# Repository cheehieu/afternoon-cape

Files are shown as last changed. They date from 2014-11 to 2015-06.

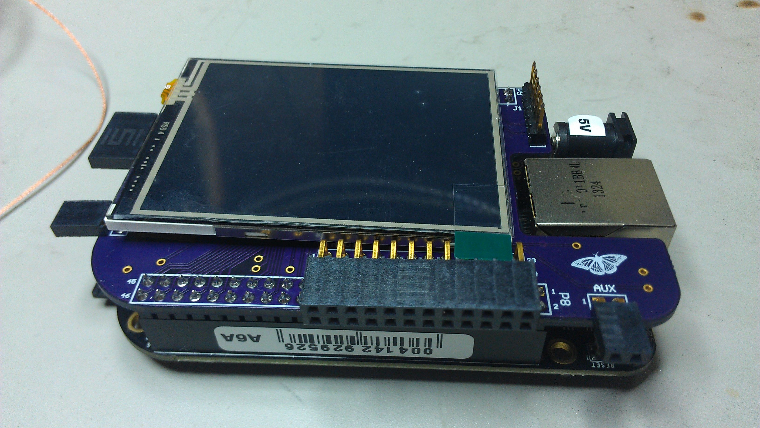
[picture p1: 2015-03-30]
images/pmcape_lcd.jpg

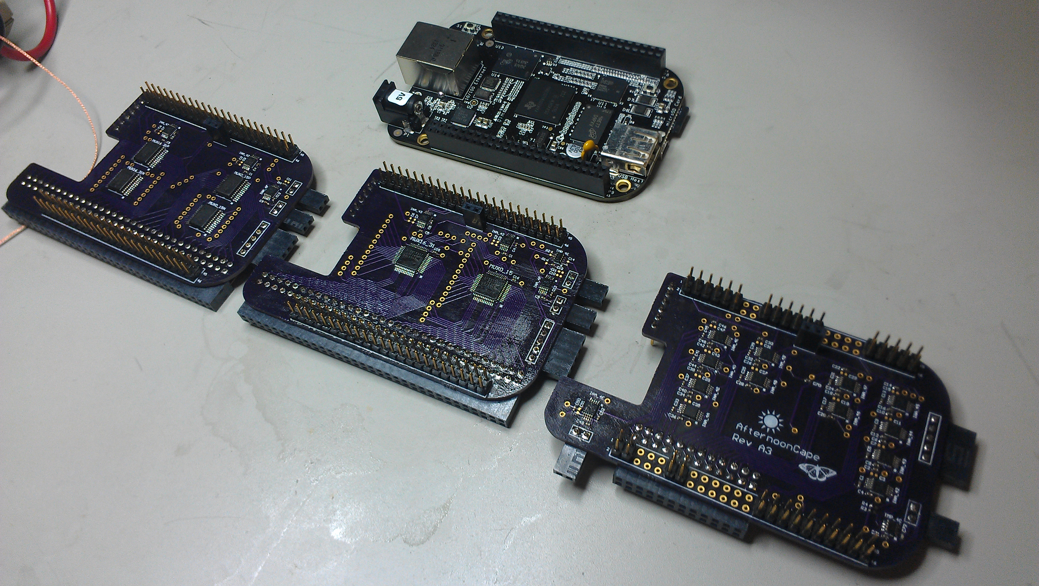
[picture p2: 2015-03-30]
images/capes_display_line.jpg

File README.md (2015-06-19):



## Overview
The AfternoonCape is a low-cost power monitoring (PM aka "afternoon") cape for the BeagleBone Black. It utilizes the INA226 instrumentation amplifier to accurately sample and monitor voltage, current, and power consumption of a given supply. This cape was created because of a need to quickly measure the active/leakage power of TI Sitara processors, without the use of hefty digital multimeter lab equipment. The AfternoonCape is a portable, relatively low-cost (~$20) solution and met the accuracy and sampling rate requirements of my team's power characterization and development tasks.

This project repository contains:

* Altium libraries, schematics, and board files
* PCB gerbers and drill files
* Bill of materials
* Standalone Bash scripts, Linux device drivers for INA226, TMP441
* GUI source, logging infrastructure

## Hardware
The AfternoonCape relies on special techniques and assumptions used for measuring power using current shunt monitors. For more information on current shunt monitors, please review this application note: [Current Shunt Monitors](http://www.ti.com/lit/ml/slyb194a/slyb194a.pdf). 



A few different board revisions were designed to test the accuracy/reliability of different signal path implementations. These "Alpha" revisions were comprised of the following: 

* *Rev. A1*: supports 32 channel inputs --> 4 discrete 16-to-1 analog muxes --> 2 instrumentation amplifiers sampling the voltage drop across a current shunt
* *Rev. A2*: supports 32 channel inputs --> 2 differential 16-to-1 analog muxes --> 2 instrumentation amplifiers sampling the voltage drop across a current shunt
* *Rev. A3*: supports 12 channel inputs --> 12 dedicated instrumentation amplifiers sampling the voltage drop across each current shunt --> LCD output

### Rev. A1:
This revision supports 32 channel inputs, which means it can measure the power consumption from 32 separate power supplies. The TI Sitara processors have advanced power designs to enable key power management techniques. One such technique is having several voltage and power domains, which can be individually turned off during periods of low activity (to save power). This type of design leads to a single-core processor having upwards of thirty separate power supplies. Thus, in order to measure total device power with voltage domain granularity, it is imperative that the measurement tool supports a sufficient amount of channel inputs.

Rev. A1 accomplishes this by utilizing the Texas Instruments CD74HC4067 16-channel analog multiplexer. This cape uses four of them to be exact. Four BBB GPIO's are interfaced to the mux select bits, which allow the proper analog signals to pass to the two INA2226's. Each INA226 handles 16 input channels. So, in order to take a total device power measurement, the cape must cycle through the mux select bits and log power data for each iteration.



Details:

* MUX_SEL0 (P8, pin 12), GPIO1_12 (0x44e10830, 0x30 offset, #44)
* MUX_SEL1 (P9, pin 23), GPIO1_17 (0x44e10844, 0x44 offset, #49)
* MUX_SEL2 (P9, pin 27), GPIO3_19 (0x44e109a4, 0x1a4 offset, #115)
* MUX_SEL3 (P9, pin 12), GPIO1_28 (0x44e10878, 0x78 offset, #60)
* INA_42 handles channels 0 through 15
* INA_43 handles channels 16 through 31
* Accuracy +/- %

### Rev. A2:
This revision also supports 32 channel inputs, but utilizes the Analog Devices ADG726 dual 16-channel analog multiplexer. The unique feature about the ADI mux vs. the TI mux is that the ADI mux can support differential operation. Thus, paired current shunt analog signals can be passed together through the same ICs. Also, only 2 of these muxes are needed due to its differential nature. The only major downside is that these ADG726 components are significantly more expensive than the TI counterpart.

Rev. A2 utilizes the same BBB GPIO control signals as mux select bits. Two INA226's are also used to measure data from 32 channel inputs.



Details:

* MUX_SEL0 (P8, pin 12)
* MUX_SEL1 (P9, pin 23)
* MUX_SEL2 (P9, pin 27)
* MUX_SEL3 (P9, pin 12)
* INA_42 handles channels 0 through 15
* INA_43 handles channels 16 through 31
* Accuracy +/- %

### Rev. A3:
This revision utilizes discrete INA226s for each channel input. It only supports 12 channels in total, but can take these power measurements simultaneously; no GPIO mux selects need to be cycled through before taking a measurement. With less channel inputs, there is routing space available for an LCD connector. The Newhaven Display International NHD-2.4-240320SF-CTXL#-FTN1 2.4" TFT LCD module was selected due to its small size and compatibility with the AM335x processor.





Details:

* INA42-INA4F handles channels 0 through 11
* Accuracy +/- %

### Rev. B1:
After testing all three Alpha revisions, it was determined that the TI analog mux (Rev. A1) was sufficiently accurate for active power characterization purposes. The Beta revision is a board shrink that incorporates lessons learned.

<!--img src="http://niftyhedgehog.com/afternoon-cape/images/pmcape_B1_oshpark_top.png" width="400"-->

<!--img src="http://niftyhedgehog.com/afternoon-cape/images/pmcape_B1_oshpark_bottom.png" width="400"-->

Details:

* Smaller vias
* Decoupling caps
* 16-channels
* LCD connector reposition
* FTDI connector for serial communication with a host PC
* AUX INA226 for dedicated system input power measurement
* PMDC connector for daisy chaining with PMDC daughter cards
* TMP441 for thermal diode junction temperature monitoring

## Software

### Standalone Bash Script
The standalone Bash script is a quick way to generate power numbers in a single instance. The script can be executed in a shell terminal on the BeagleBone Black running a [Debian](http://beagleboard.org/project/debian/) Linux distribution (has support for '[bc](http://www.gnu.org/software/bc/manual/html_mono/bc.html)' by default). The following is a high-level procedure for taking power measurements with the AfternoonCape:

1. Initialize INA226, GPIOs
2. Take shunt and bus voltage measurements for all supplies
3. Average the measurement values and store
4. Calculate power
5. Output to console and/or log file
6. Cleanup

```bash
...
#EVM Specific
declare -a SUPPLIES=('VDD_CORE' 'VDD_MPU' 'VDDS_DDR' 'V1_8D' 'V3_3D' 'VDDS_DDR_M
EM');
declare -a RES=(0.05 0.05 0.05 0.1 0.1 0.05);

...

echo $mux_sel0 > /sys/class/gpio/gpio44/value
echo $mux_sel1 > /sys/class/gpio/gpio49/value
echo $mux_sel2 > /sys/class/gpio/gpio115/value
echo $mux_sel3 > /sys/class/gpio/gpio60/value

...

#Collect shunt voltage measurement
shuntv=$(i2cget -y 1 $MUX1_INA_ADDR $SHUNTV_REG w)
let "temp = $shuntv >> 8"
let "temp2 = $shuntv << 8 | $temp"
let "shuntv = $temp2 & 0xffff"
shuntv=$(echo "$shuntv*0.0025" | bc)
MUX1_SHUNTV[j]=$shuntv

...

#Collect bus voltage measurement
busv=$(i2cget -y 1 $MUX1_INA_ADDR $BUSV_REG w)
let "temp = $busv >> 8"
let "temp2 = $busv << 8 | $temp"
let "busv = $temp2 & 0xffff"
busv=$(echo "$busv*0.00125" | bc)
MUX1_BUSV[k]=$busv

...

#Calculate power
SUPPLIES_CURRENT[i]=$(echo "${SUPPLIES_SHUNTV[i]}/${RES[i]}" | bc -l)
SUPPLIES_POWER[i]=$(echo "${SUPPLIES_CURRENT[i]}*${SUPPLIES_BUSV[i]}" |
total_power=$(echo "$total_power+${SUPPLIES_POWER[$x]}" | bc)
```

#### Usage:
```bash
root@beaglebone:~# ./testA2.sh
```

* loadmod afternoon-cape.ko EVM=am437xGP.txt
* Bash shell scripts using sysfs GPIO
* PMDC I2C protocol

### Accuracy
The afternoon-cape is a good, low-cost solution for getting "ballpark" power measurements. It works best in medium power use cases, where the current shunt voltage is >1mV; voltages on the micro-volt level are less accurately interpreted through the analog mux.
Some tests were done on the AM335x GP EVM to determine accuracy. Compared with a $1000+ Keithley Digital Multimeter with a $500 switching multiplexer module, the accuracy was comparable.

* Table comparison

## 3D
### AfternoonCape
<iframe width="640" height="480" src="https://sketchfab.com/models/0be9d541e4cb438f95a222904efbc644/embed" frameborder="0" allowfullscreen mozallowfullscreen="true" webkitallowfullscreen="true" onmousewheel=""></iframe>

<p style="font-size: 13px; font-weight: normal; margin: 5px; color: #4A4A4A;">
    <a href="https://sketchfab.com/models/0be9d541e4cb438f95a222904efbc644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" target="_blank" style="font-weight: bold; color: #1CAAD9;">AfternoonCape Rev. A3</a>
    by <a href="https://sketchfab.com/hieu?utm_source=oembed&utm_medium=embed&utm_campaign=0be9d541e4cb438f95a222904efbc644" target="_blank" style="font-weight: bold; color: #1CAAD9;">hieu</a>
    on <a href="https://sketchfab.com?utm_source=oembed&utm_medium=embed&utm_campaign=0be9d541e4cb438f95a222904efbc644" target="_blank" style="font-weight: bold; color: #1CAAD9;">Sketchfab</a>
</p>

### AfternoonCape Mounted on a BBB
<iframe width="640" height="480" src="https://sketchfab.com/models/db15b2ddc1894994b0886cfb680e3865/embed" frameborder="0" allowfullscreen mozallowfullscreen="true" webkitallowfullscreen="true" onmousewheel=""></iframe>

<p style="font-size: 13px; font-weight: normal; margin: 5px; color: #4A4A4A;">
    <a href="https://sketchfab.com/models/db15b2ddc1894994b0886cfb680e3865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" target="_blank" style="font-weight: bold; color: #1CAAD9;">AfternoonCape with BBB</a>
    by <a href="https://sketchfab.com/hieu?utm_source=oembed&utm_medium=embed&utm_campaign=db15b2ddc1894994b0886cfb680e3865" target="_blank" style="font-weight: bold; color: #1CAAD9;">hieu</a>
    on <a href="https://sketchfab.com?utm_source=oembed&utm_medium=embed&utm_campaign=db15b2ddc1894994b0886cfb680e3865" target="_blank" style="font-weight: bold; color: #1CAAD9;">Sketchfab</a>
</p>

## To Do:
* Update README with Accuracy and BOM materials
* Complete design for Rev. B, assemble & test
* Ensure script compatibility with latest v3.14 kernel
* Qt GUI and data logging over a network connection to a host PC
* Cost comparison with other *more expensive* solutions (DARA, ACME, PMDC, Spectrum Digital, Tick)

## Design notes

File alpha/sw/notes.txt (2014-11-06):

i2cdetect -y -r 1			#detect i2c slaves on bus 1 (I2C2 19/20)
#40: 40 41 42 43 -- -- -- -- -- -- -- -- -- -- -- -- 
#50: -- -- -- -- UU UU UU UU -- -- -- -- -- -- -- --

#SHUNT VOLTAGE = DEC(msbyte_lsbyte) * 2.5 UV
i2cget -y 1 0x40 0x01 w		#gets shunt voltage in hex 0x[lsbyte][msbyte]

#BUS VOLTAGE = DEC(msbyte_lsbyte) * 1.25 mV
i2cget -y 1 0x40 0x02 w		#gets bus voltage in hex 0x[lsbyte][msbyte]

#CALIBRATION to set shunt resistor value
#based on equation 1 in datasheet

#CURRENT and POWER need averaging to be set in config register

i2cset -y 1 0x40 0x00 0x2747 w	#sets config register to have averaging 64x

######################## THERMAL DIODE ########################
#TMP435 both address lines connected to GND
i2cset -y 1 0x4c 0x03 0x04 b#set extended range in config register
i2cget -y 1 0x4c 0x01 w		#read lowbyteHighbyte of remote temp

i2cd
#TMP441 both address lines connected to GND
i2cset -y 1 0x4c 0x9 0x4	#extended temp range
i2cset -y 1 0x4c 0xA 0x1C	#resistance, length
i2cset -y 1 0x4c 0xB 0x7	#conversion rate
i2cset -y 1 0x4c 0xC 0xf	#beta compensation
i2cset -y 1 0x4c 0x21 0x8	#n-correction

i2cget -y 1 0x4c 0x1 w		#read lowbyteHighbyte of remote sensor
i2cget -y 1 0x4c 0x1 b		#read Highbyte of remote sensor
i2cget -y 1 0x4c 0x11 b		#read lowbyte of remote sensor
i2cget -y 1 0x4c 0x0 w		#read lowbyteHighbyte of local sensor
i2cget -y 1 0x4c 0x0 b		#read Highbyte of local sensor
i2cget -y 1 0x4c 0x10 b		#read lowbyte of local sensor

i2cset -y 1 0x4c 0xFC 0x1	#software reset

#################### PSEUDO-CODE #############################
- If available, read in EVM config file
-- Parse for supply names, resistor values, etc.
-- Save values in structure
- Initialize INA226
- Initialize TMP441
- Initialize LCD
- Based on supply(s) selected, read corresponding channel, calculate power, store in structure
- Data dump feature
- Just temperature measurement feature (check boxes)
- AUX power
- Adjust speed of reading new data (1 Hz, 5 Hz, 10 Hz, 25 Hz, 50 Hz)
- GUI links to Wiki power consumption summaries
- Clear button

This is a small guide for those who want to write kernel drivers for I2C
or SMBus devices, using Linux as the protocol host/master (not slave).

To set up a driver, you need to do several things. Some are optional, and
some things can be done slightly or completely different. Use this as a
guide, not as a rule book!

General remarks
===============

Try to keep the kernel namespace as clean as possible. The best way to
do this is to use a unique prefix for all global symbols. This is
especially important for exported symbols, but it is a good idea to do
it for non-exported symbols too. We will use the prefix `foo_' in this
tutorial.

The driver structure
====================

Usually, you will implement a single driver structure, and instantiate
all clients from it. Remember, a driver structure contains general access
routines, and should be zero-initialized except for fields with data you
provide.  A client structure holds device-specific information like the
driver model device node, and its I2C address.

static struct i2c_device_id foo_idtable[] = {
	{ "foo", my_id_for_foo },
	{ "bar", my_id_for_bar },
	{ }
};

MODULE_DEVICE_TABLE(i2c, foo_idtable);

static struct i2c_driver foo_driver = {
	.driver = {
		.name	= "foo",
	},

	.id_table	= foo_idtable,
	.probe		= foo_probe,
	.remove		= foo_remove,
	/* if device autodetection is needed: */
	.class		= I2C_CLASS_SOMETHING,
	.detect		= foo_detect,
	.address_list	= normal_i2c,

	.shutdown	= foo_shutdown,	/* optional */
	.suspend	= foo_suspend,	/* optional */
	.resume		= foo_resume,	/* optional */
	.command	= foo_command,	/* optional, deprecated */
}

The name field is the driver name, and must not contain spaces.  It
should match the module name (if the driver can be compiled as a module),
although you can use MODULE_ALIAS (passing "foo" in this example) to add
another name for the module.  If the driver name doesn't match the module
name, the module won't be automatically loaded (hotplug/coldplug).

All other fields are for call-back functions which will be explained
below.

Extra client data
=================

Each client structure has a special `data' field that can point to any
structure at all.  You should use this to keep device-specific data.

	/* store the value */
	void i2c_set_clientdata(struct i2c_client *client, void *data);

	/* retrieve the value */
	void *i2c_get_clientdata(const struct i2c_client *client);

Note that starting with kernel 2.6.34, you don't have to set the `data' field
to NULL in remove() or if probe() failed anymore. The i2c-core does this
automatically on these occasions. Those are also the only times the core will
touch this field.

Accessing the client
====================

Let's say we have a valid client structure. At some time, we will need
to gather information from the client, or write new information to the
client.

I have found it useful to define foo_read and foo_write functions for this.
For some cases, it will be easier to call the i2c functions directly,
but many chips have some kind of register-value idea that can easily
be encapsulated.

The below functions are simple examples, and should not be copied
literally.

int foo_read_value(struct i2c_client *client, u8 reg)
{
	if (reg < 0x10)	/* byte-sized register */
		return i2c_smbus_read_byte_data(client, reg);
	else		/* word-sized register */
		return i2c_smbus_read_word_data(client, reg);
}

int foo_write_value(struct i2c_client *client, u8 reg, u16 value)
{
	if (reg == 0x10)	/* Impossible to write - driver error! */
		return -EINVAL;
	else if (reg < 0x10)	/* byte-sized register */
		return i2c_smbus_write_byte_data(client, reg, value);
	else			/* word-sized register */
		return i2c_smbus_write_word_data(client, reg, value);
}

Probing and attaching
=====================

The Linux I2C stack was originally written to support access to hardware
monitoring chips on PC motherboards, and thus used to embed some assumptions
that were more appropriate to SMBus (and PCs) than to I2C.  One of these
assumptions was that most adapters and devices drivers support the SMBUS_QUICK
protocol to probe device presence.  Another was that devices and their drivers
can be sufficiently configured using only such probe primitives.

As Linux and its I2C stack became more widely used in embedded systems
and complex components such as DVB adapters, those assumptions became more
problematic.  Drivers for I2C devices that issue interrupts need more (and
different) configuration information, as do drivers handling chip variants
that can't be distinguished by protocol probing, or which need some board
specific information to operate correctly.

Device/Driver Binding
---------------------

System infrastructure, typically board-specific initialization code or
boot firmware, reports what I2C devices exist.  For example, there may be
a table, in the kernel or from the boot loader, identifying I2C devices
and linking them to board-specific configuration information about IRQs
and other wiring artifacts, chip type, and so on.  That could be used to
create i2c_client objects for each I2C device.

I2C device drivers using this binding model work just like any other
kind of driver in Linux:  they provide a probe() method to bind to
those devices, and a remove() method to unbind.

	static int foo_probe(struct i2c_client *client,
			     const struct i2c_device_id *id);
	static int foo_remove(struct i2c_client *client);

Remember that the i2c_driver does not create those client handles.  The
handle may be used during foo_probe().  If foo_probe() reports success
(zero not a negative status code) it may save the handle and use it until
foo_remove() returns.  That binding model is used by most Linux drivers.

The probe function is called when an entry in the id_table name field
matches the device's name. It is passed the entry that was matched so
the driver knows which one in the table matched.

Device Creation
---------------

If you know for a fact that an I2C device is connected to a given I2C bus,
you can instantiate that device by simply filling an i2c_board_info
structure with the device address and driver name, and calling
i2c_new_device().  This will create the device, then the driver core will
take care of finding the right driver and will call its probe() method.
If a driver supports different device types, you can specify the type you
want using the type field.  You can also specify an IRQ and platform data
if needed.

Sometimes you know that a device is connected to a given I2C bus, but you
don't know the exact address it uses.  This happens on TV adapters for
example, where the same driver supports dozens of slightly different
models, and I2C device addresses change from one model to the next.  In
that case, you can use the i2c_new_probed_device() variant, which is
similar to i2c_new_device(), except that it takes an additional list of
possible I2C addresses to probe.  A device is created for the first
responsive address in the list.  If you expect more than one device to be
present in the address range, simply call i2c_new_probed_device() that
many times.

The call to i2c_new_device() or i2c_new_probed_device() typically happens
in the I2C bus driver. You may want to save the returned i2c_client
reference for later use.

Device Detection
----------------

Sometimes you do not know in advance which I2C devices are connected to
a given I2C bus.  This is for example the case of hardware monitoring
devices on a PC's SMBus.  In that case, you may want to let your driver
detect supported devices automatically.  This is how the legacy model
was working, and is now available as an extension to the standard
driver model.

You simply have to define a detect callback which will attempt to
identify supported devices (returning 0 for supported ones and -ENODEV
for unsupported ones), a list of addresses to probe, and a device type
(or class) so that only I2C buses which may have that type of device
connected (and not otherwise enumerated) will be probed.  For example,
a driver for a hardware monitoring chip for which auto-detection is
needed would set its class to I2C_CLASS_HWMON, and only I2C adapters
with a class including I2C_CLASS_HWMON would be probed by this driver.
Note that the absence of matching classes does not prevent the use of
a device of that type on the given I2C adapter.  All it prevents is
auto-detection; explicit instantiation of devices is still possible.

Note that this mechanism is purely optional and not suitable for all
devices.  You need some reliable way to identify the supported devices
(typically using device-specific, dedicated identification registers),
otherwise misdetections are likely to occur and things can get wrong
quickly.  Keep in mind that the I2C protocol doesn't include any
standard way to detect the presence of a chip at a given address, let
alone a standard way to identify devices.  Even worse is the lack of
semantics associated to bus transfers, which means that the same
transfer can be seen as a read operation by a chip and as a write
operation by another chip.  For these reasons, explicit device
instantiation should always be preferred to auto-detection where
possible.

Device Deletion
---------------

Each I2C device which has been created using i2c_new_device() or
i2c_new_probed_device() can be unregistered by calling
i2c_unregister_device().  If you don't call it explicitly, it will be
called automatically before the underlying I2C bus itself is removed, as a
device can't survive its parent in the device driver model.

Initializing the driver
=======================

When the kernel is booted, or when your foo driver module is inserted,
you have to do some initializing. Fortunately, just registering the
driver module is usually enough.

static int __init foo_init(void)
{
	return i2c_add_driver(&foo_driver);
}
module_init(foo_init);

static void __exit foo_cleanup(void)
{
	i2c_del_driver(&foo_driver);
}
module_exit(foo_cleanup);

The module_i2c_driver() macro can be used to reduce above code.

module_i2c_driver(foo_driver);

Note that some functions are marked by `__init'.  These functions can
be removed after kernel booting (or module loading) is completed.
Likewise, functions marked by `__exit' are dropped by the compiler when
the code is built into the kernel, as they would never be called.

Driver Information
==================

/* Substitute your own name and email address */
MODULE_AUTHOR("Frodo Looijaard <frodol@dds.nl>"
MODULE_DESCRIPTION("Driver for Barf Inc. Foo I2C devices");

/* a few non-GPL license types are also allowed */
MODULE_LICENSE("GPL");

Power Management
================

If your I2C device needs special handling when entering a system low
power state -- like putting a transceiver into a low power mode, or
activating a system wakeup mechanism -- do that in the suspend() method.
The resume() method should reverse what the suspend() method does.

These are standard driver model calls, and they work just like they
would for any other driver stack.  The calls can sleep, and can use
I2C messaging to the device being suspended or resumed (since their
parent I2C adapter is active when these calls are issued, and IRQs
are still enabled).

System Shutdown
===============

If your I2C device needs special handling when the system shuts down
or reboots (including kexec) -- like turning something off -- use a
shutdown() method.

Again, this is a standard driver model call, working just like it
would for any other driver stack:  the calls can sleep, and can use
I2C messaging.

Command function
================

A generic ioctl-like function call back is supported. You will seldom
need this, and its use is deprecated anyway, so newer design should not
use it.

Sending and receiving
=====================

If you want to communicate with your device, there are several functions
to do this. You can find all of them in <linux/i2c.h>.

If you can choose between plain I2C communication and SMBus level
communication, please use the latter. All adapters understand SMBus level
commands, but only some of them understand plain I2C!

Plain I2C communication
-----------------------

	int i2c_master_send(struct i2c_client *client, const char *buf,
			    int count);
	int i2c_master_recv(struct i2c_client *client, char *buf, int count);

These routines read and write some bytes from/to a client. The client
contains the i2c address, so you do not have to include it. The second
parameter contains the bytes to read/write, the third the number of bytes
to read/write (must be less than the length of the buffer, also should be
less than 64k since msg.len is u16.) Returned is the actual number of bytes
read/written.

	int i2c_transfer(struct i2c_adapter *adap, struct i2c_msg *msg,
			 int num);

This sends a series of messages. Each message can be a read or write,
and they can be mixed in any way. The transactions are combined: no
stop bit is sent between transaction. The i2c_msg structure contains
for each message the client address, the number of bytes of the message
and the message data itself.

You can read the file `i2c-protocol' for more information about the
actual I2C protocol.

SMBus communication
-------------------

	s32 i2c_smbus_xfer(struct i2c_adapter *adapter, u16 addr,
			   unsigned short flags, char read_write, u8 command,
			   int size, union i2c_smbus_data *data);

This is the generic SMBus function. All functions below are implemented
in terms of it. Never use this function directly!

	s32 i2c_smbus_read_byte(struct i2c_client *client);
	s32 i2c_smbus_write_byte(struct i2c_client *client, u8 value);
	s32 i2c_smbus_read_byte_data(struct i2c_client *client, u8 command);
	s32 i2c_smbus_write_byte_data(struct i2c_client *client,
				      u8 command, u8 value);
	s32 i2c_smbus_read_word_data(struct i2c_client *client, u8 command);
	s32 i2c_smbus_write_word_data(struct i2c_client *client,
				      u8 command, u16 value);
	s32 i2c_smbus_read_block_data(struct i2c_client *client,
				      u8 command, u8 *values);
	s32 i2c_smbus_write_block_data(struct i2c_client *client,
				       u8 command, u8 length, const u8 *values);
	s32 i2c_smbus_read_i2c_block_data(struct i2c_client *client,
					  u8 command, u8 length, u8 *values);
	s32 i2c_smbus_write_i2c_block_data(struct i2c_client *client,
					   u8 command, u8 length,
					   const u8 *values);

These ones were removed from i2c-core because they had no users, but could
be added back later if needed:

	s32 i2c_smbus_write_quick(struct i2c_client *client, u8 value);
	s32 i2c_smbus_process_call(struct i2c_client *client,
				   u8 command, u16 value);
	s32 i2c_smbus_block_process_call(struct i2c_client *client,
					 u8 command, u8 length, u8 *values);

All these transactions return a negative errno value on failure. The 'write'
transactions return 0 on success; the 'read' transactions return the read
value, except for block transactions, which return the number of values
read. The block buffers need not be longer than 32 bytes.

You can read the file `smbus-protocol' for more information about the
actual SMBus protocol.

General purpose routines
========================

Below all general purpose routines are listed, that were not mentioned
before.

	/* Return the adapter number for a specific adapter */
	int i2c_adapter_id(struct i2c_adapter *adap);

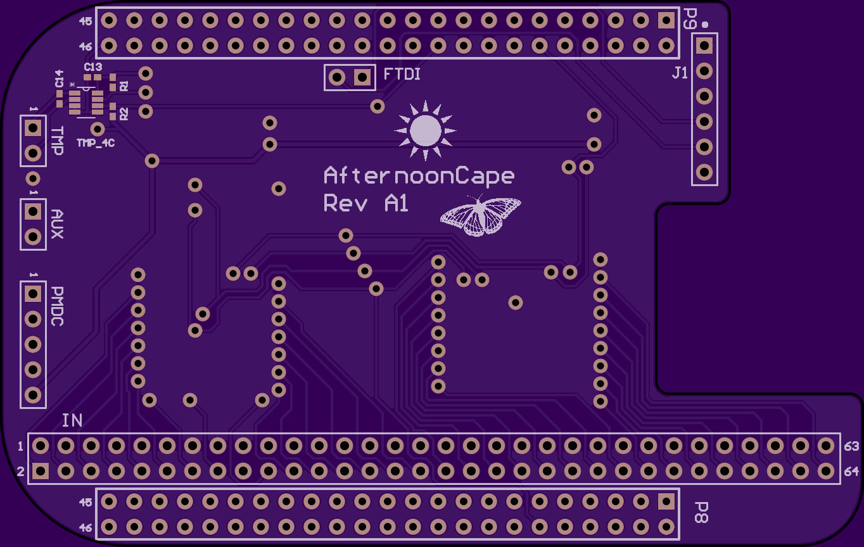
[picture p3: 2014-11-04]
images/pmcape_A1_oshpark_top.png

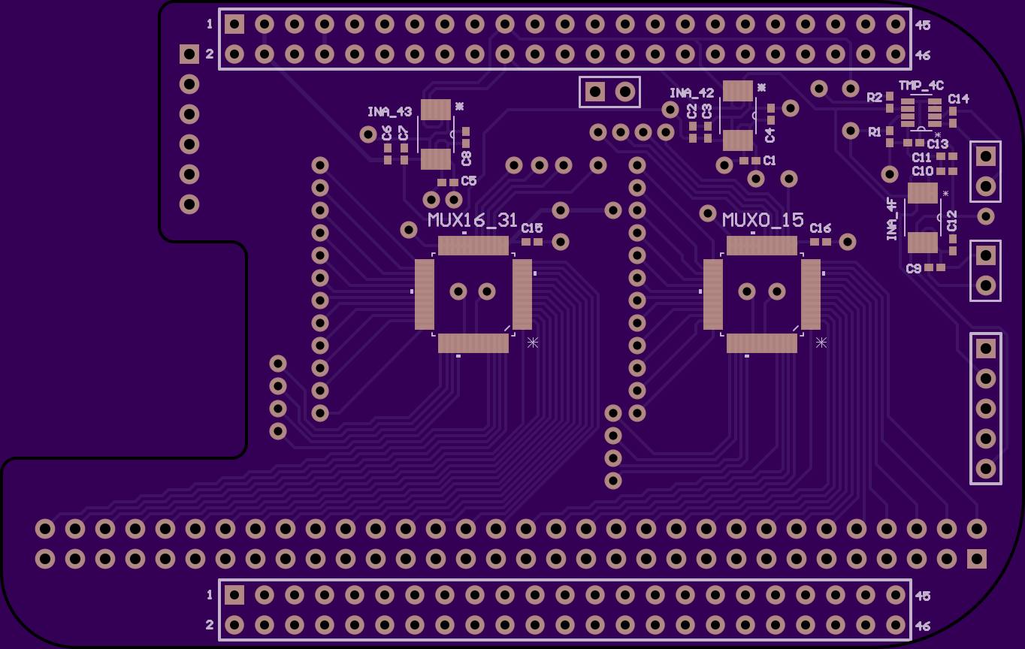
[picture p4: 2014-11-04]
images/pmcape_A2_oshpark_bottom.png

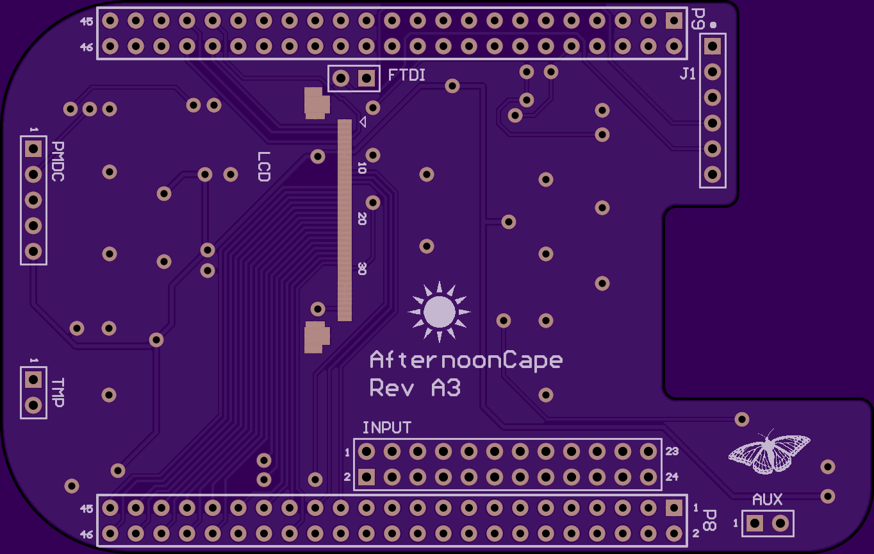
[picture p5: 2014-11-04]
images/pmcape_A3_oshpark_top.png

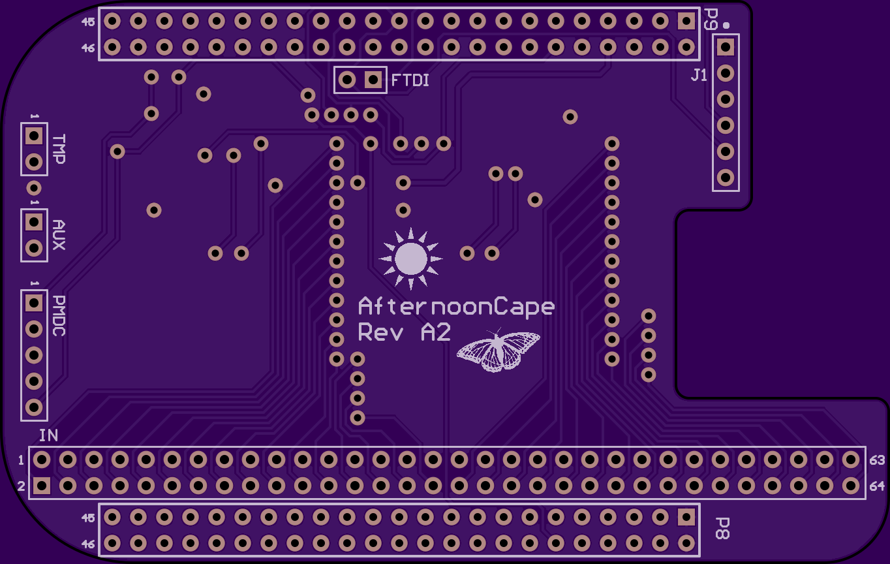
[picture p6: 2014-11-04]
images/pmcape_A2_oshpark_top.png

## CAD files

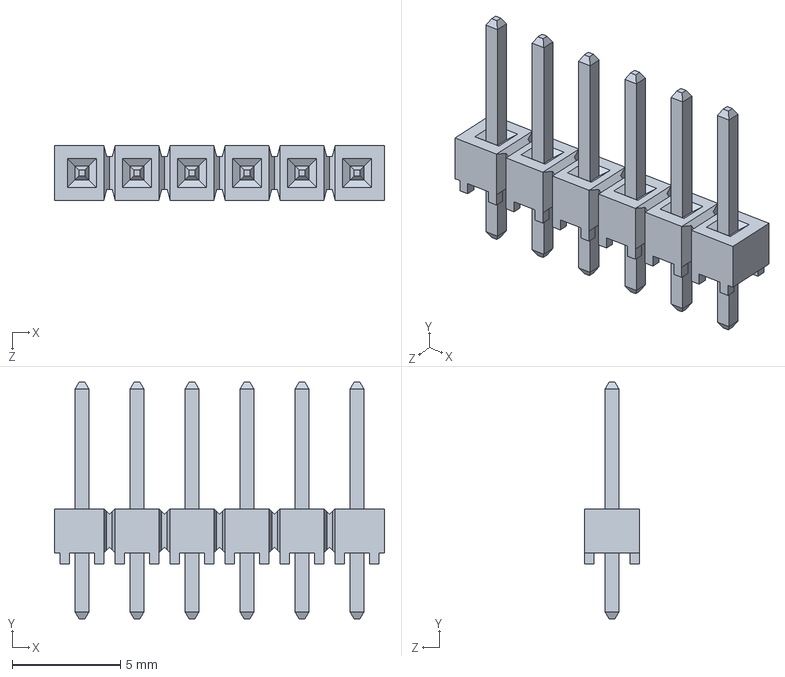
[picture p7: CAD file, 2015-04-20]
3d/Samtec/TSW-106-07-X-S.step
15.2 x 10.9 x 2.54 mm

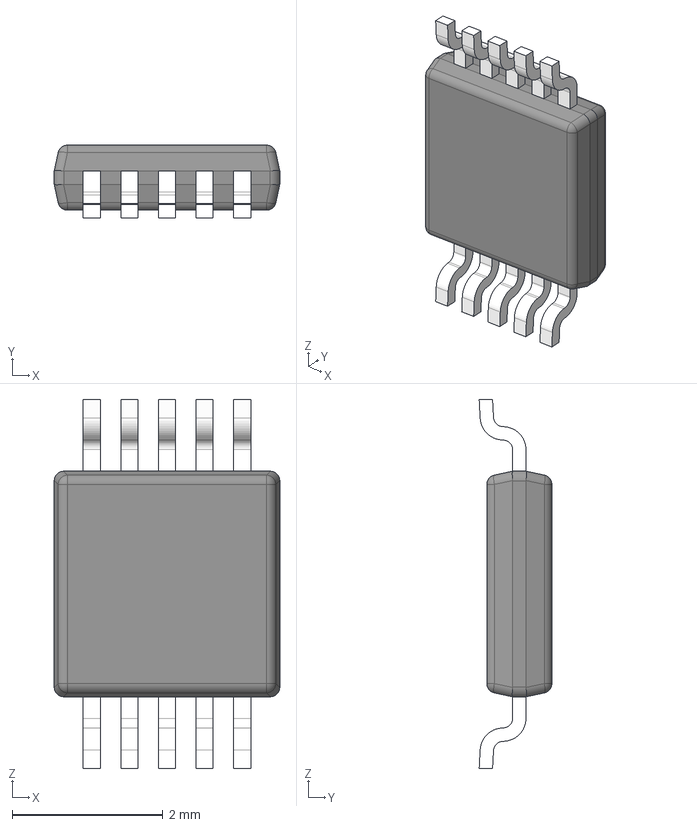
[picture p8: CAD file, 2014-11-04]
docs/ina226/mub10a.stp
3.00 x 0.965 x 4.90 mm
BODY_MUB10A
LEAD_MUB10A x 10

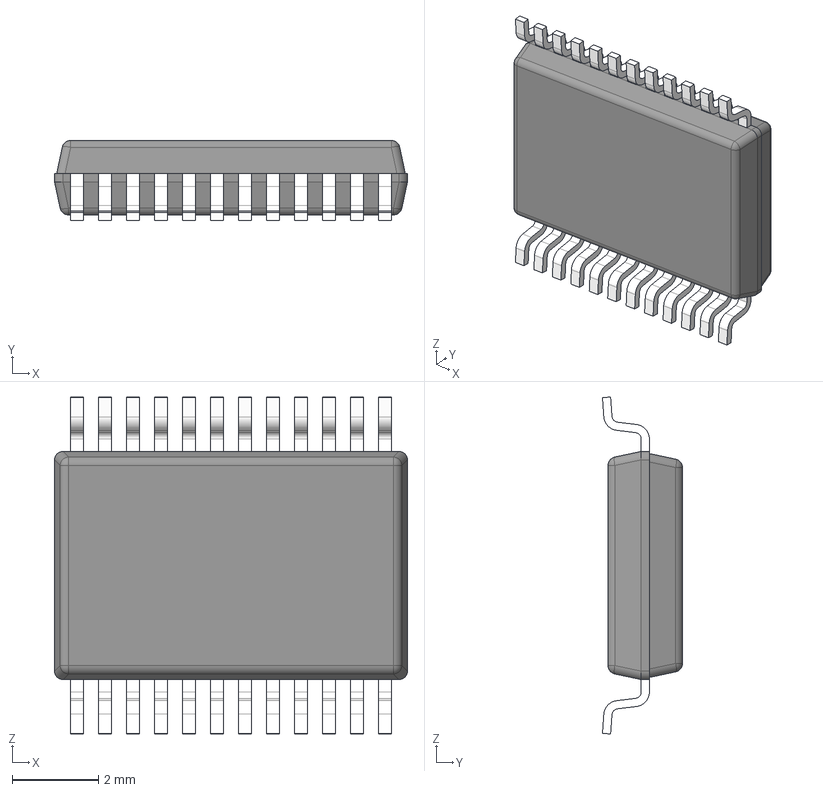
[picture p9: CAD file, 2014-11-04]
docs/mux/DB0024A.stp
8.20 x 1.86 x 7.83 mm
BODY_MSA24
LEAD_MSA24 x 24

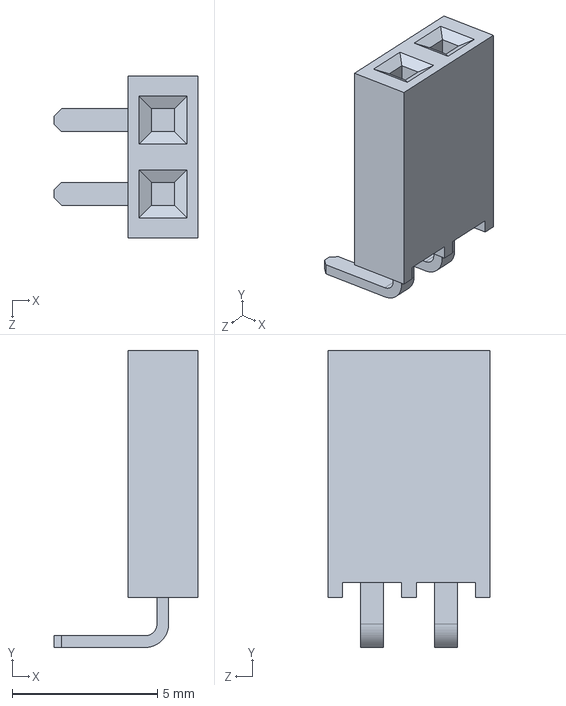
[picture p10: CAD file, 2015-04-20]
3d/Samtec/SSW-102-02-X-S-RA.step
4.95 x 10.2 x 5.59 mm

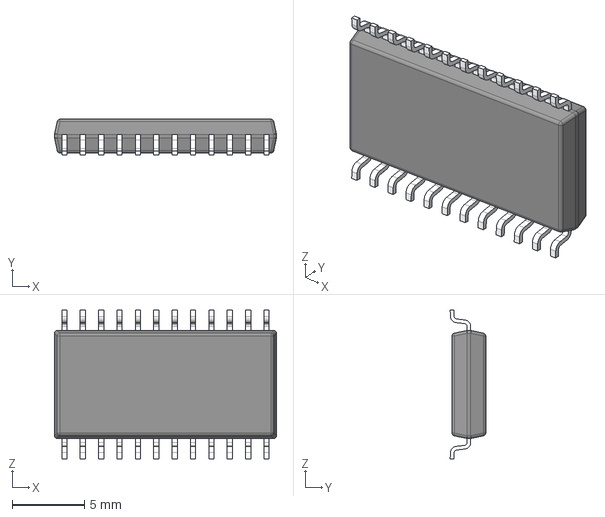
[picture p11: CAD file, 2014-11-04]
docs/mux/DW0024A.stp
15.3 x 2.46 x 10.3 mm
BODY_M24B
LEAD_M24B x 24

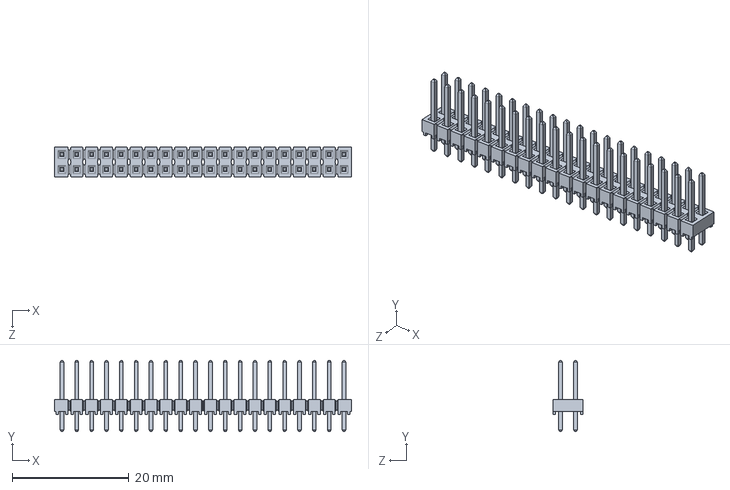
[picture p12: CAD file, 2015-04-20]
3d/Samtec/TSW-120-24-X-D.step
50.8 x 12.2 x 5.08 mm

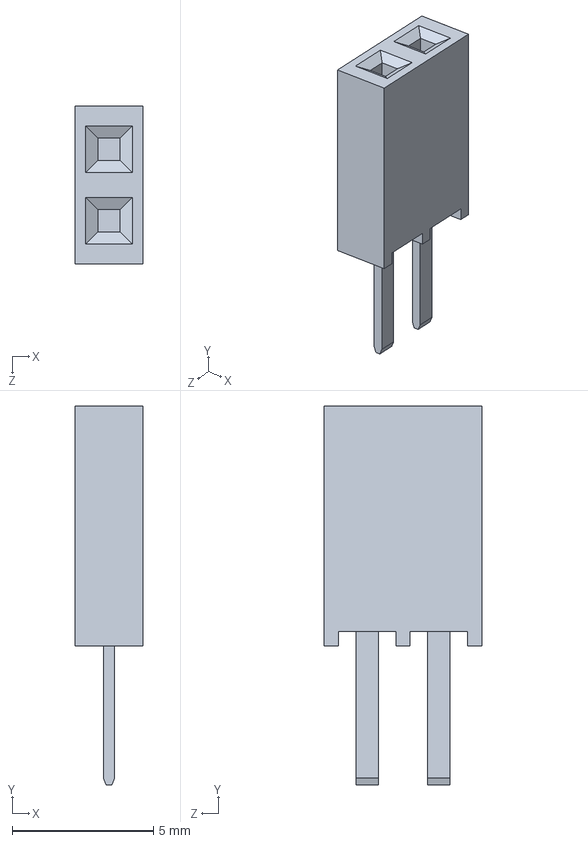
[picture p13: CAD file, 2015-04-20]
3d/Samtec/SSW-102-02-X-S.step
2.41 x 13.4 x 5.59 mm

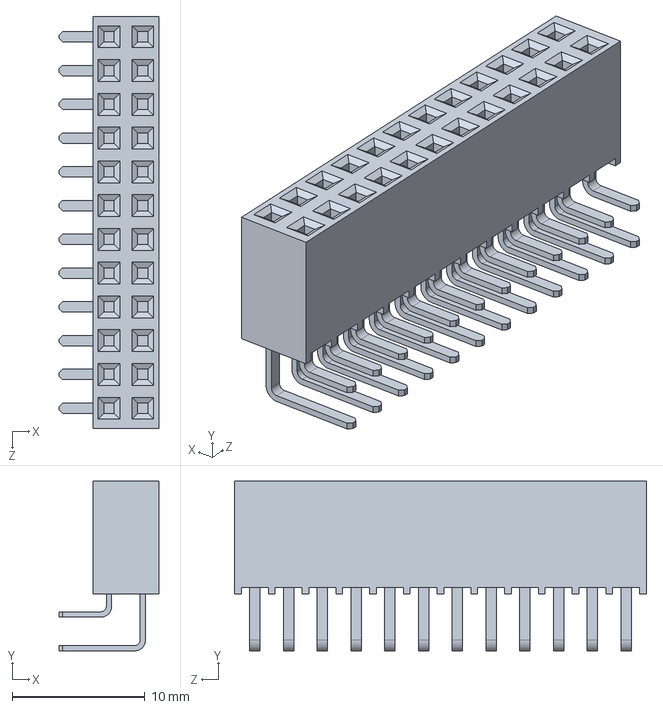
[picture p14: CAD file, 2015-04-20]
3d/Samtec/SSW-112-02-X-D-RA.step
7.49 x 12.8 x 31.0 mm

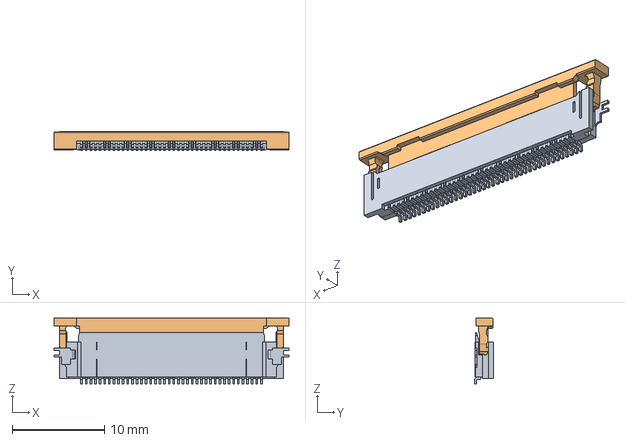
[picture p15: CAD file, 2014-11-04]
docs/display/541324062.stp
25.5 x 2.05 x 7.15 mm

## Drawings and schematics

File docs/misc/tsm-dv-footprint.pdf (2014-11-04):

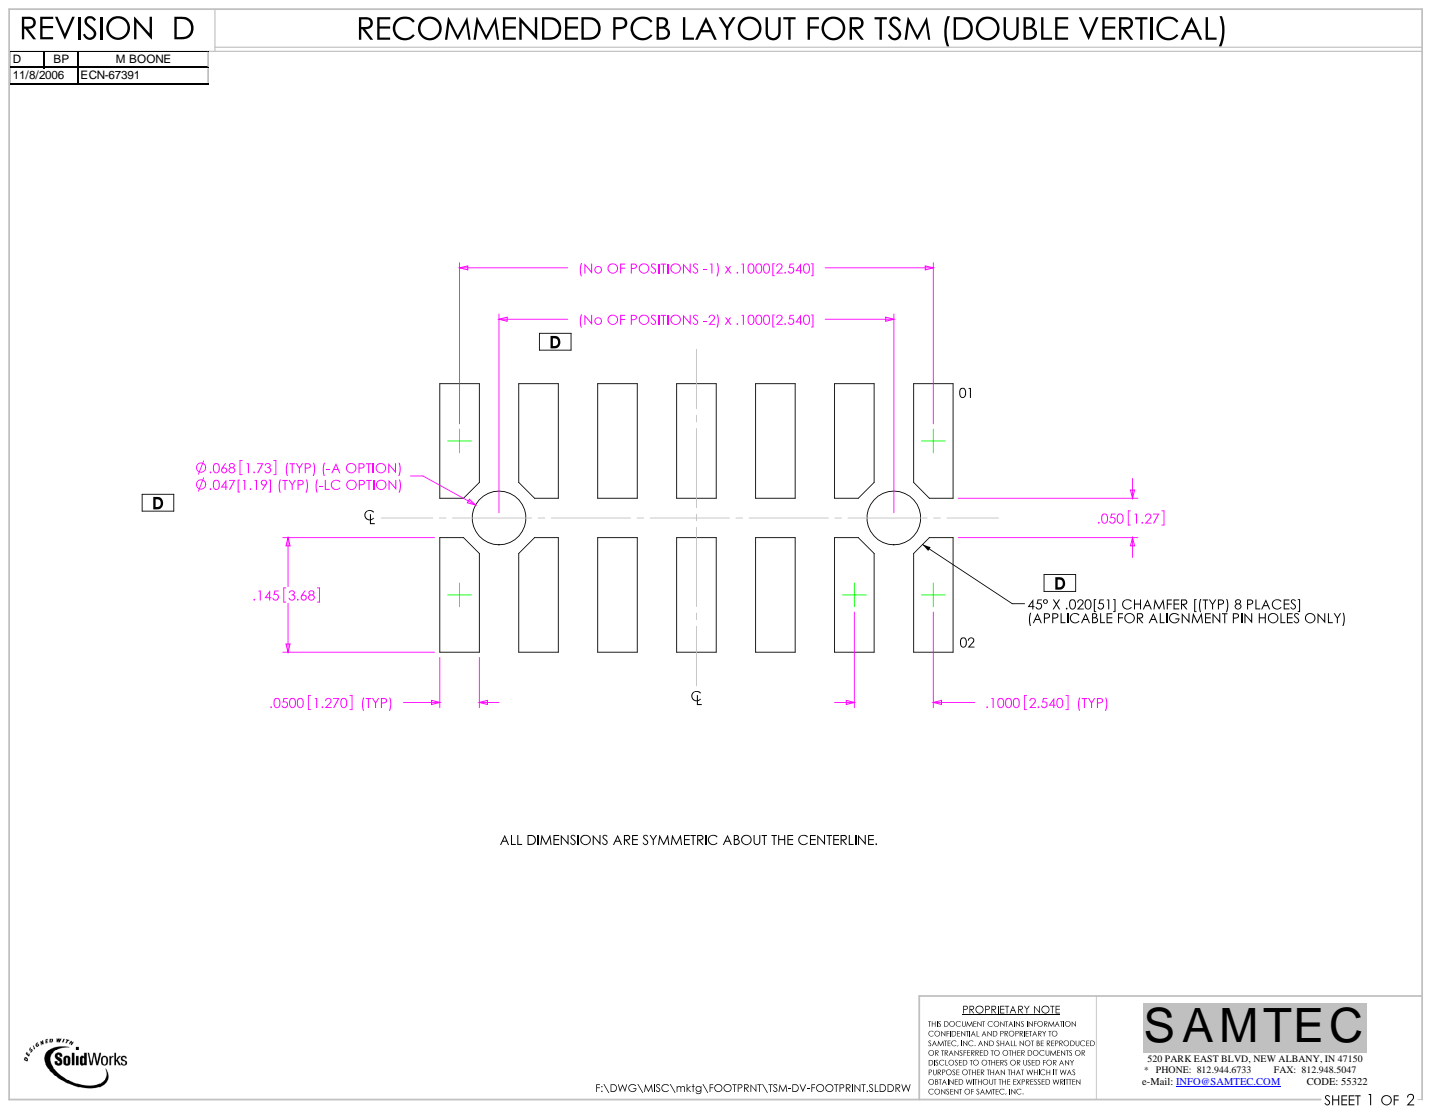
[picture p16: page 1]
* PHONE: 812.944.6733; FAX: 812.948.5047; e-Mail: INFO@SAMTEC.COM; CODE: 55322 D; M BOONE; ECN-67391

SAMTEC 520 PARK EAST BLVD, NEW ALBANY, IN 47150

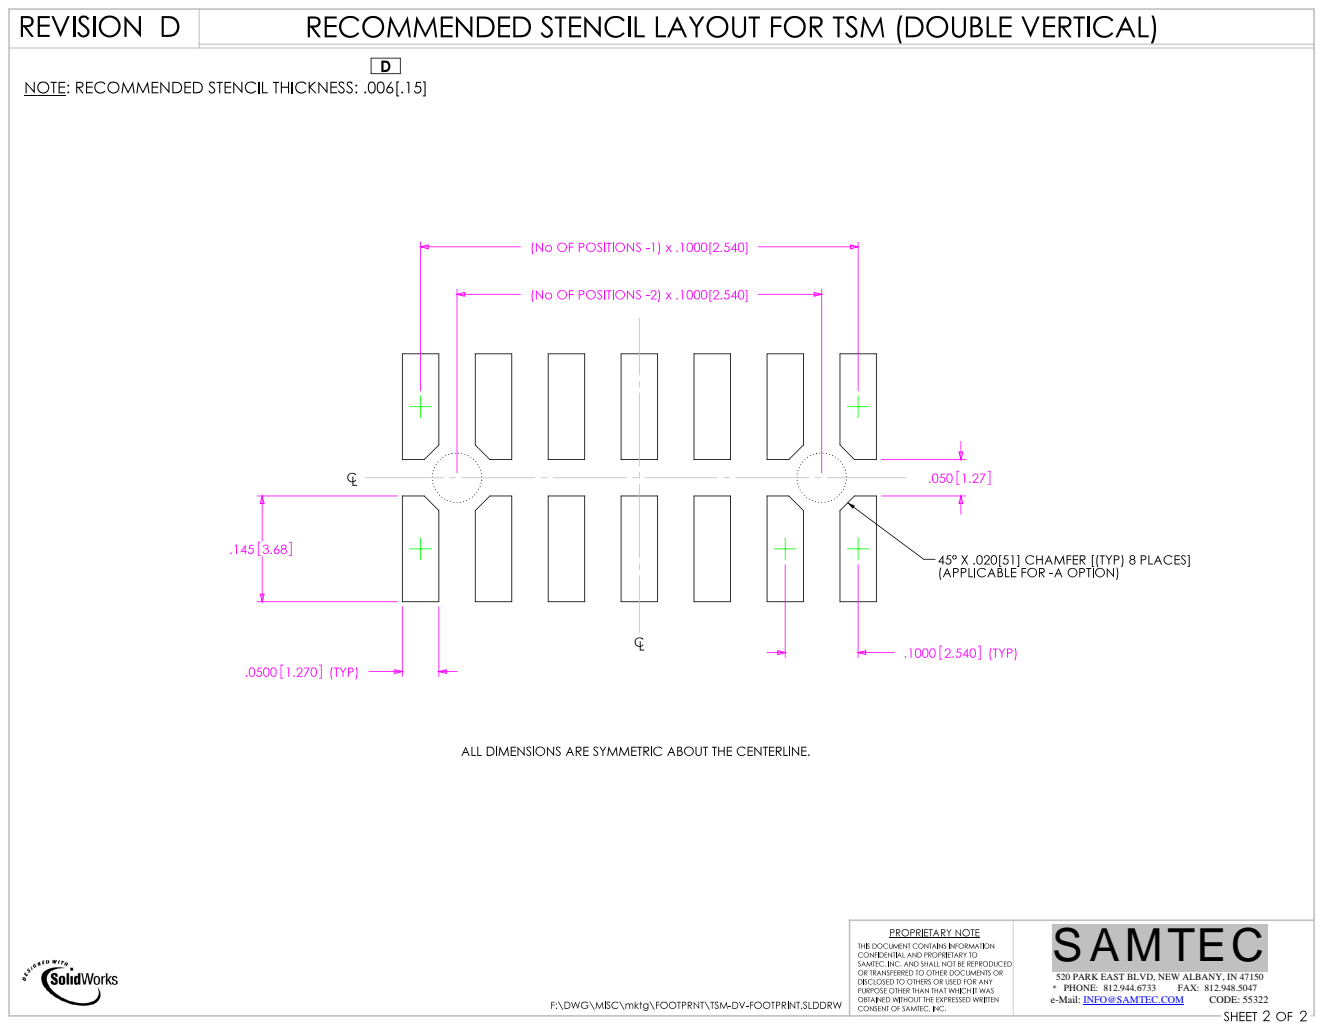
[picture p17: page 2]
* PHONE: 812.944.6733; FAX: 812.948.5047; e-Mail: INFO@SAMTEC.COM; CODE: 55322

SAMTEC 520 PARK EAST BLVD, NEW ALBANY, IN 47150

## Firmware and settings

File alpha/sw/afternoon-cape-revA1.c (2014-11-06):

#include <stdio.h>

#define PMDC_INA1_ADDR	0x40
#define PMDC_INA2_ADDR	0x41
#define CAPE_INA1_ADDR	0x42
#define CAPE_INA2_ADDR	0x43
#define TMP441_ADDR	0x4C
#define AUX_INA_ADDR	0x4F

#define TI_MUX1_GPIO	0x1
#define TI_MUX2_GPIO	0x2
#define TI_MUX3_GPIO	0x3
#define TI_MUX4_GPIO	0x4
#define ADI_MUX1_GPIO	0x1
#define ADI_MUX2_GPIO	0x2

//unsigned with a -64C offset (ranges from -64 to 191C)
#define EXT_HIGH_BYTE_C_CONV(a)	a-64;
#define LOW_BYTE_C_CONV(b)	b/16*0.0625;	//b is unsigned

main() 	{
	//Initialize INA226's
	#CALIBRATION to set shunt resistor value
	#based on equation 1 in datasheet

	#CURRENT and POWER need averaging to be set in config register
	i2cset -y 1 0x40 0x00 0x2747 w	#sets config register to have averaging 64x

	//Initialize TMP441
	//extended range, conversion rate, beta compensation, n-factor correction
	i2cset -y 1 0x4c 0x9 0x04	#extended temp range
	

	//Initialize LCD and GUI (light-tft server)
	//Set capture options (frequency, select supplies to omit)
	//set display options (show history, last 30 seconds, real time,)

	//Read in EVM/*evm files
	//save values to arrays of structs

	
	//Take a power measurement
	#SHUNT VOLTAGE = DEC(msbyte_lsbyte) * 2.5 UV
	i2cget -y 1 0x40 0x01 w		#gets shunt voltage in hex 0x[lsbyte][msbyte]

	#BUS VOLTAGE = DEC(msbyte_lsbyte) * 1.25 mV
	i2cget -y 1 0x40 0x02 w		#gets bus voltage in hex 0x[lsbyte][msbyte]


	//Take a thermal measurement (remote and local)
	//show both celsius and fahrenheit
	i2cget -y 1 0x4c 0x1 w		#read lowbyteHighbyte of remote sensor
	

	//Print measurement to console in spreadsheet copy/paste format
	//Output a log
	//Output last data capture


}

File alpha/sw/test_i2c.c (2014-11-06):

#include <errno.h>
#include <string.h>
#include <stdio.h>
#include <stdlib.h>
#include <unistd.h>
#include <linux/i2c-dev.h>
#include <linux/i2c.h>
#include <sys/ioctl.h>
#include <sys/types.h>
#include <sys/stat.h>
#include <fcntl.h>

main() {
	printf("\nHello World!\n");
	
	int file;
	int adapter_nr = 1; 
	char filename[20];
	
	snprintf(filename, 19, "/dev/i2c-%d", adapter_nr);
	file = open(filename, O_RDWR);
	if (file < 0) {
        	exit(1);
	}

	int addr = 0x40;
	if (ioctl(file, I2C_SLAVE, addr) < 0) {
		exit(1);
	}  

  	char ina_reg = 0x0; 
    	int res;
      	char buf[10];

	// Using I2C Write, equivalent of i2c_smbus_write_word_data(file, register, 0x6543)
	buf[0] = ina_reg;
	buf[1] = 0xff;
	buf[2] = 0x4f;
	if (write(file, buf, 3) != 3) {
	}

	// Using I2C Read, equivalent of i2c_smbus_read_byte(file) 
	if (read(file, buf, 1) != 1) {
		/* ERROR HANDLING: i2c transaction failed */
	} else {
		/* buf[0] contains the read byte */
		printf("Read: 0x%04x\n", buf[0]);
	}

	res = i2c_smbus_read_word_data(file, ina_reg);
	if (res < 0) {
	} else {
		printf("Read: 0x%04x\n", res);
	}

	printf("\nGoodbye World!\n");
}

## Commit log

2014-11-01 added alpha board files and gerbers
    [AfternoonCape_RevA1_TImux.PcbDoc, AfternoonCape_RevA1_TImux.PrjPCB, AfternoonCape_RevA1_TImux.SchDoc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]
2014-11-04 added docs and images; restructured directory hierarchy
    [2014-02-12_15-55-34.PcbLib, 2014-02-12_15-55-34.SchLib, 541324062.stp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]
2014-11-06 Added prototyping bash scripts and prelim c/board files.
2015-04-20 Added headers and BBB to 3D
    [SSW-102-02-X-S-RA.step, SSW-102-02-X-S.step, SSW-112-02-X-D-RA.step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]
2015-09-03 Updated schematic libraries.
    [AfternoonCape_RevA1_TImux.PrjPCB, AfternoonCape_RevA1_TImux.SchDoc, AfternoonCape_RevA2_ADImux.SchDoc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]
